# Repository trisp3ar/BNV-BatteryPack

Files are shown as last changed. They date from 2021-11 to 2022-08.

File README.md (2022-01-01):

*Harware status*: passing

*Model status*: passing

# BNV-BatteryPack

This is the Bootleg Night Vision Battery Pack, based on L3HARRIS BATTERY POWER SUPPLY for PVS 31, GPNVG 18, etc.

This design is a work in progress.

## Open Source Night Vision

This design is an open source design and everyone is welcome to build, modify and experiment on their own. It is intended to be used with the BPNVGs but can also be used with anything that uses 12 V input. Everything you need will be listed in the documentation.

## Specifications: (datasheet will be added with Release 1.0)

- Output voltage      : 12 V
- Batteries           : 4 x 18650 or CR123A
- Current Output      : 1.25 A
- protection index    : IP68 (planned/unverified)
- Dimensions          : 111 mm y 97 mm x36 mm
- Weight (empty)      : 115 g

01.01.2022

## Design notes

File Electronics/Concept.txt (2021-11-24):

Voltage Output	: 12 V
Batteries		: 18650, CR123A
Current delivery: Display	: 50 mA
				  Sensor	: 95 mA
				  Total		: 580 mA

Voltage Regulator IC		: MIC2937A-12WU, TL751M12QKVURQ1
reverse polarity protection : BAS20,235
Battery contact sping		: 5202
Battery contact flat		: 5224
Power Switch				: APEM 21136NA
Power Jack					: MIC2937A-12WU
Power Plug					: S761KS15

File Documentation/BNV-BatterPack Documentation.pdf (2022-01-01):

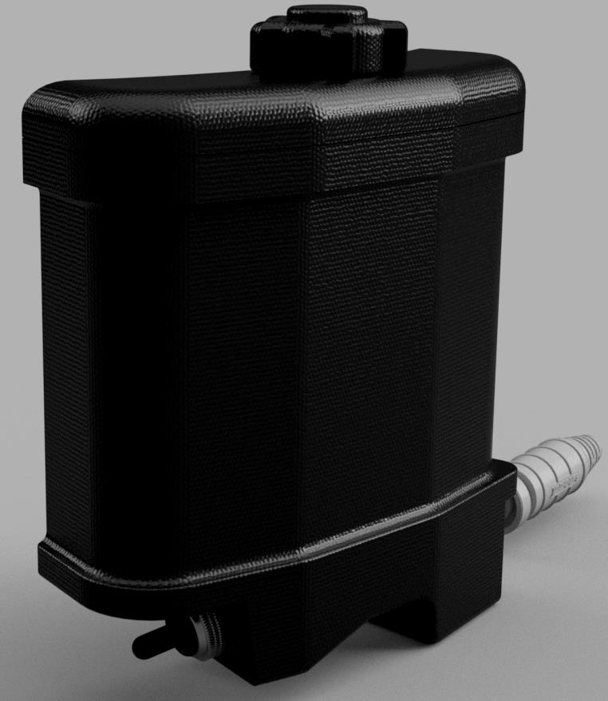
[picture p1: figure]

Gregor Hermani | 01.01.2022

# BNV-Battery Pack

Bootleg Night Vision Battery Pack

General Description

The BNV-Battery Pack is an open-source battery pack designed for use with night vision equipment in mind. It is meant to be a DIY solution for replacing a common analog night vision battery pack. With a 3D-printed case it is an easy and cheap solution. No shortcuts have been made in performance compared to commercially available night vision battery packs. It is waterproof, dustproof and airproof, as well as shock and weather resistant. The bigger body will except larger cells and can therefor provide up to 14 000 mAh.

Specifications

Voltage Output | : 12 V
Batteries | : 4 x 18650, 8 x CR123A
Current output | : 1.25 A
Protection class | : IP68 (planned/unverified)
Dimensions | : 111 mm x 97 mm x 36 mm
Weight (empty) | : 115 g

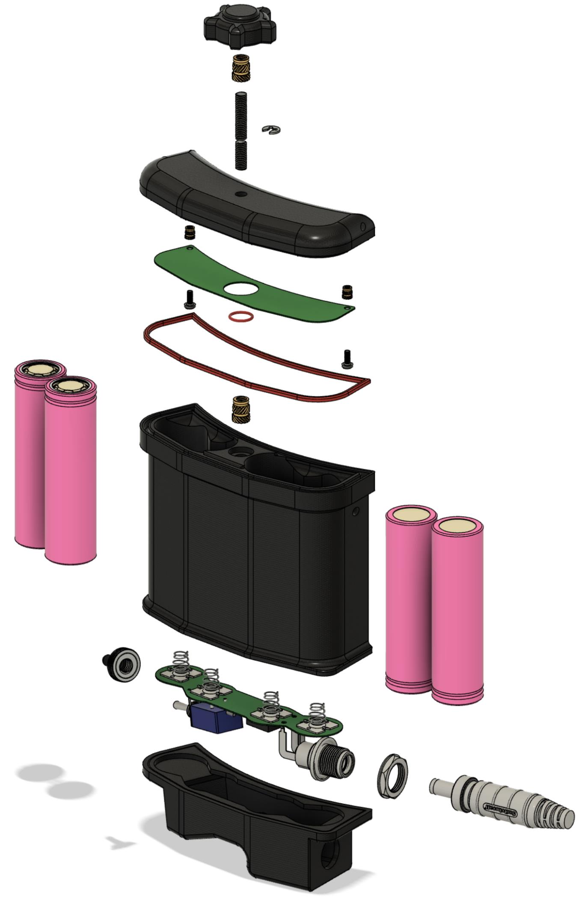
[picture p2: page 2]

Assembly

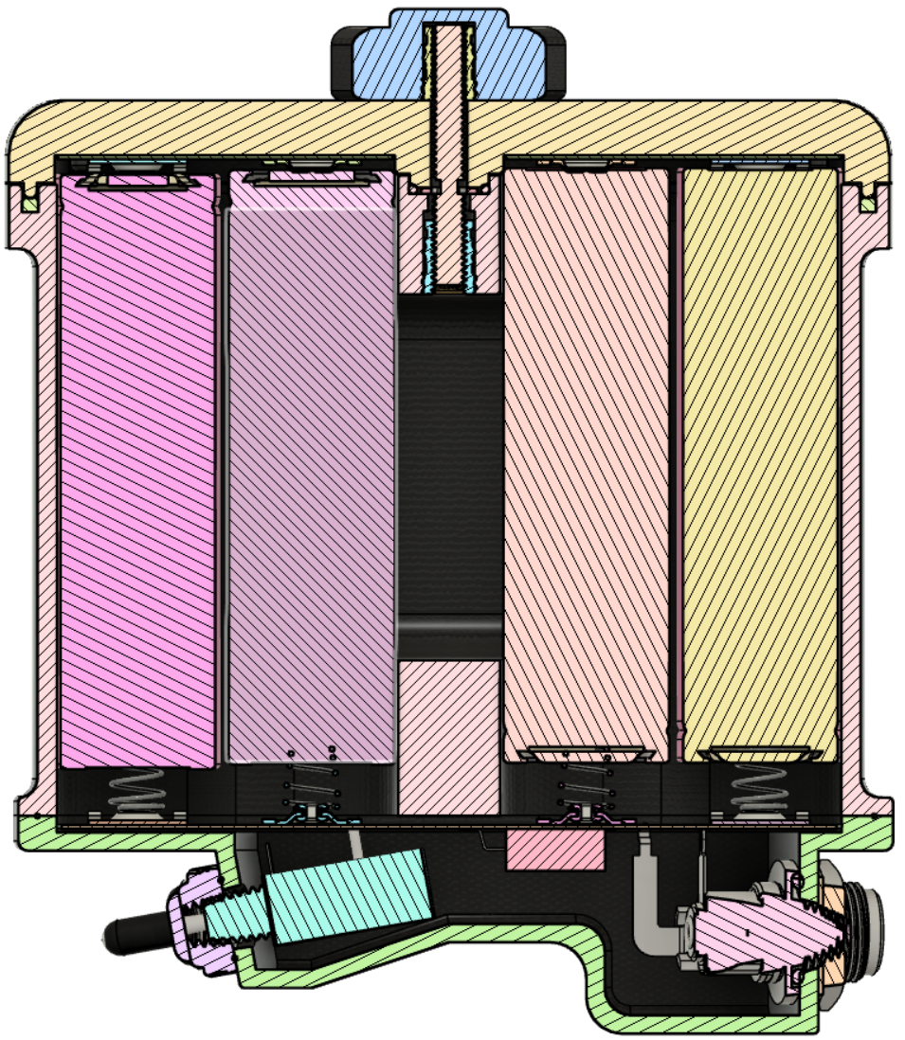
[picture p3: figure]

Development data and configuration

The designed purpose for this battery pack is power supply for night vision utilizing cameras for image acquisition and NTSC/PAL displays for video output.

Usable hardware with corresponding power consumption data and calculation for Bootleg Panoramic Night Vision Goggles:

manufacturer | part | model | current draw @ 12 V
Adafruit | display | 911 | 50 mA
Adafruit | display | 910 | 50 mA
Foxeer | camera | Micro Night Cat 3 | 95 mA
Runcam | camera | Night Eagle 2 Pro | 90 mA

Calculating for panoramic night vision with 4 camaras and 4 displays in parallel with highest current draw.

4 x 50 mA

4 x 95 mA

580 mA

To calculate for additional IR illumination, it is useful to add at least 20 % of power output capability.

battery pack schematic

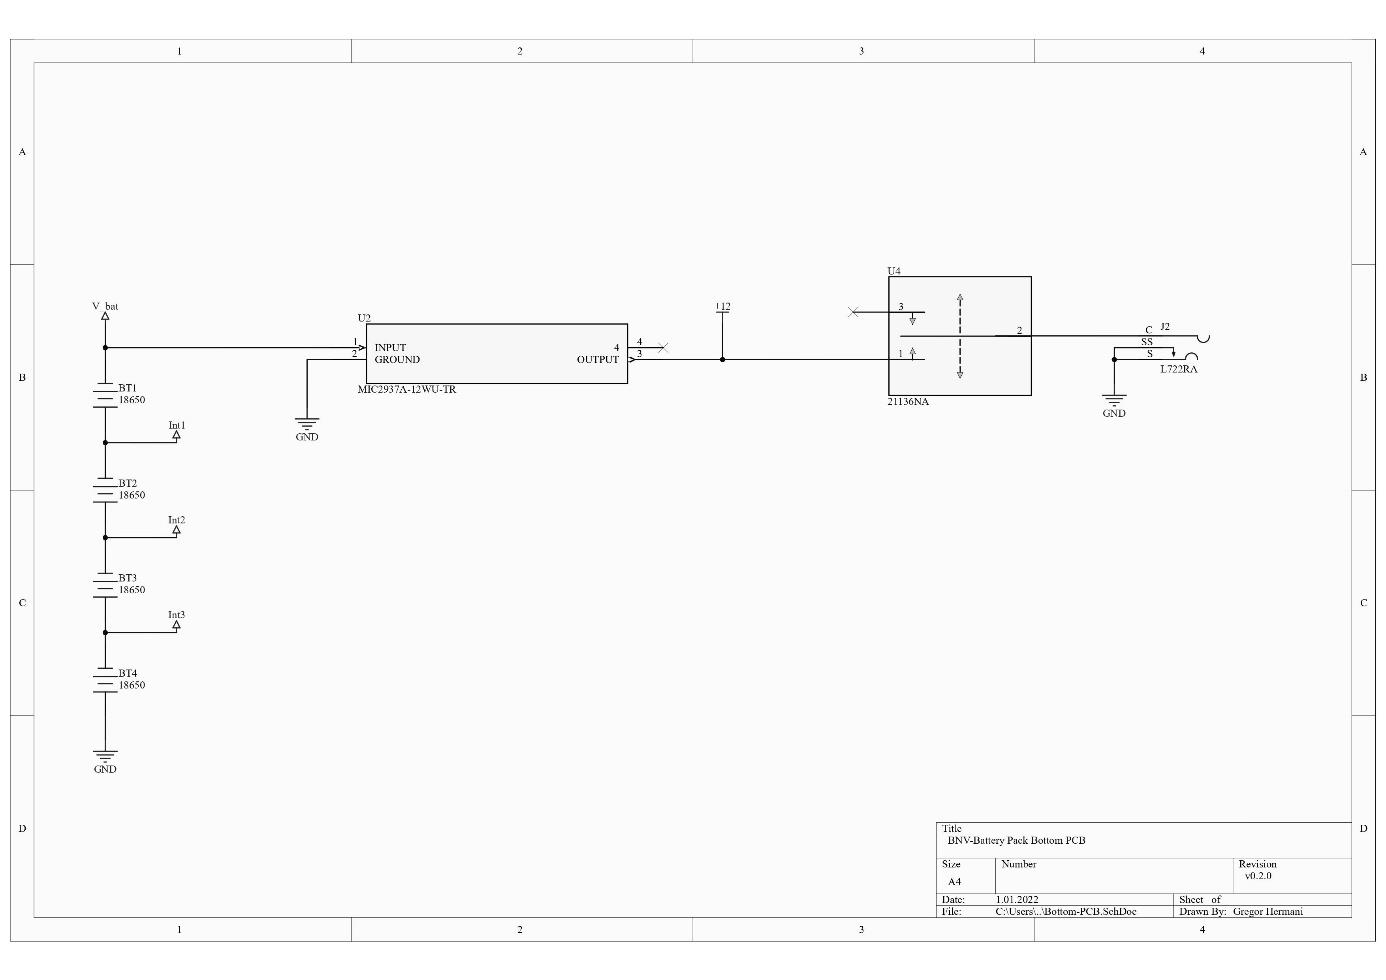
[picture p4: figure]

Version tracking and change log

v0.1.0 - initial version

v0.2.0 - changed cell configuration from 2P2R to 4R, removed diode

ToDo

- undercurrent protection
- relocate switch
- add assembly guide

Disclaimer:

This an open-source project, all information is provided without warranty.

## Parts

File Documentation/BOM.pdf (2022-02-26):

amount | part | specifications | manufacturer | MPN | component
1 | Body | 3D print | - | -
1 | Top | 3D print | - | -
1 | Bottom | 3D print | - | -
1 | Secure Nob | 3D print | - | -
1 | M4 Bolt | DIN 913 M4x25 mm | - | -
1 | safety washer | 2.3 mm DIN 6799 | - | -
1 | top gasket | 70A | - | -
1 | Secure Nob Gasket | 7 x 1 mm | - | -
2 | screw | M2x6 ISO 7380-1 | - | -
2 | M4 thread insert | brass | - | -
2 | M2 thread insert | brass | - | -
1 | connector cap | - | Switchcraft | JCAP
1 | sealing boot | 1/4-40UNS | Apem | U1331 or similar
1 | PCB | - | - | -
1 | connector | Pin OD: 2 mm, IP68 | Switchcraft | L722RAS
| connector cover | - | Switchcraft | JCAP
1 | switch | On-On | Apem | 21136NA
1 | voltage regulator IC | In: 2-26 V, Out: 12 V | Microchip | MIC2940A-12WU
4 | battery contact spring | A, AA | Keystone Electronics | 5202
1 | Kapton/Polyimid tape | < 10 cm | - | -
1 | PCB | - | - | -
4 | battery contact | A, AA | Keystone Electronics | 5224
1 | connector | Pin OD: 2 mm, IP68 | Switchcraft | S761KS15
1 | cable | two stand, OD: 4 mm | - | -
1 | glue | 2 component epoxy | Loctite | 4090
1 | potting compound | 2 component epoxy | Höhne | PU 500/2 | recommended connector cable

This is a complete BOM for the BNV-Battery Pack. All parts needed are listed, sorted by component. All parts marked with "-" are subject to personal selection due to self-manufacturing or logistics/location.

Top PCB

Bodywork

Bottom PCB

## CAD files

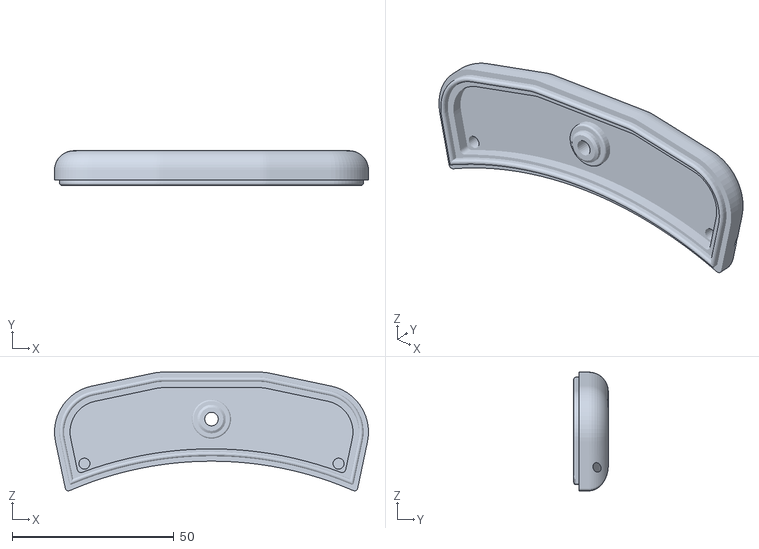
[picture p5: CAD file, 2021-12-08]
CAD/3D Printing Files/BNV-BatteryPack_Top.stl
97.0 x 10.7 x 36.7

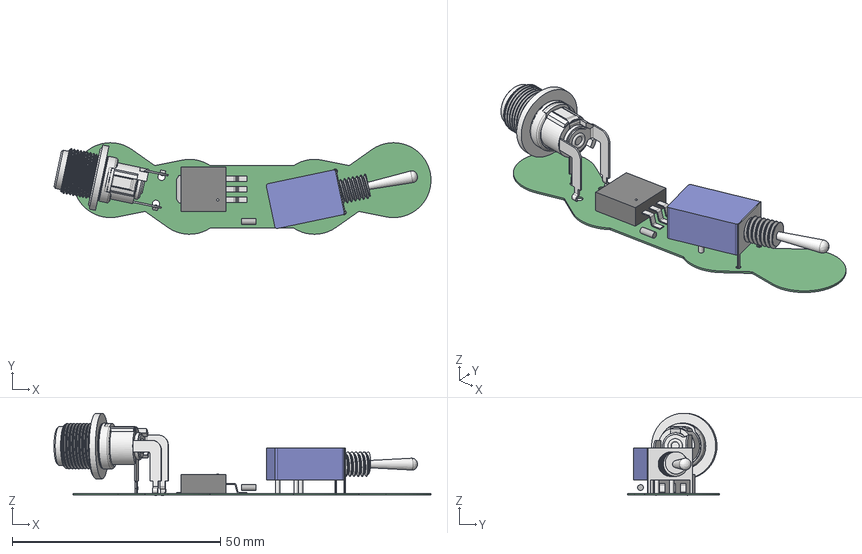
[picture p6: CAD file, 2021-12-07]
Electronics/BNV-BatteryPack_Bottom-PCB/Bottom-PCB_v0.2.0.step
90.5 x 22.0 x 19.8 mm
2113xN_v1
L722RAS

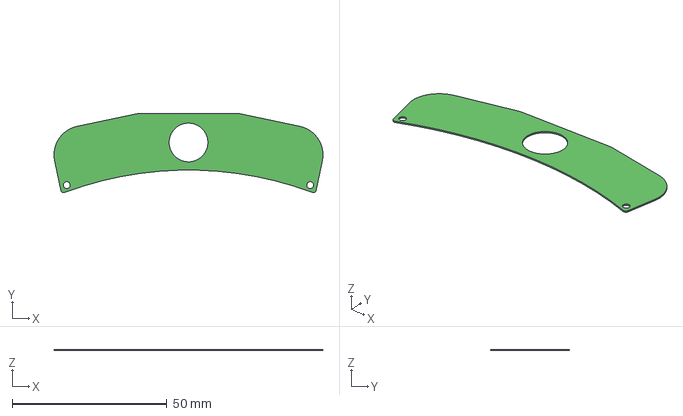
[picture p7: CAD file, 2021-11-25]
Electronics/BNV-BatteryPack_Top-PCB/Top-PCB.step
86.8 x 25.6 x 0.411 mm

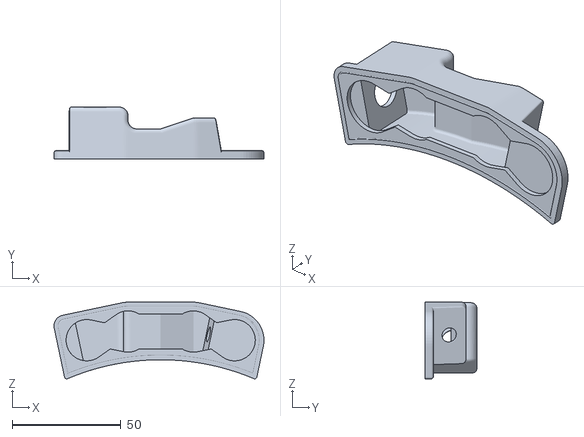
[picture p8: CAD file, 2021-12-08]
CAD/3D Printing Files/BNV-BatteryPack_Bottom.stl
96.6 x 23.8 x 35.3

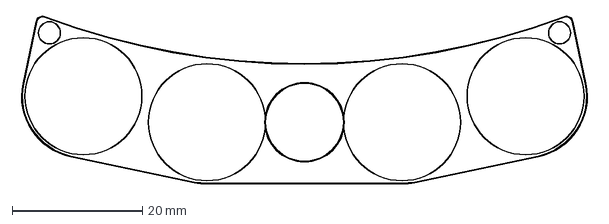
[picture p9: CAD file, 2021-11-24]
Electronics/BNV-BatteryPack_Top-PCB/Top-PCB_v0.2.0.dxf
88.8 x 25.8 mm

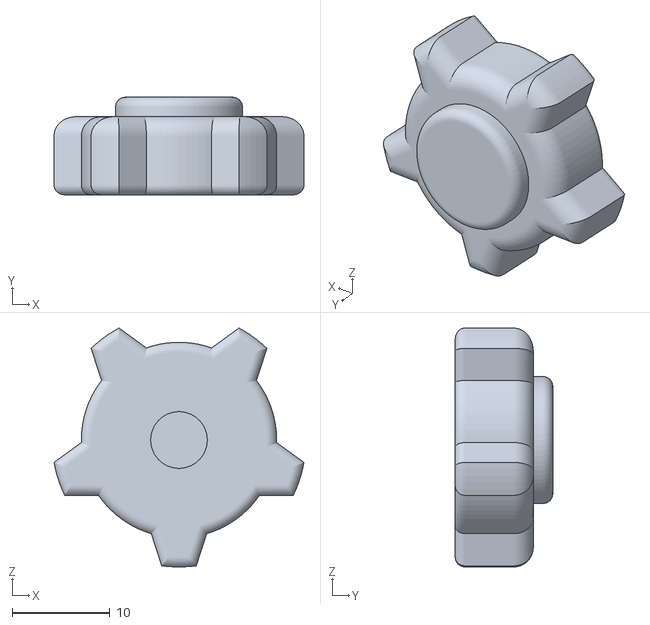
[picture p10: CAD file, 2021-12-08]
CAD/3D Printing Files/BNV-BatteryPack_SecureNob.stl
25.6 x 10.0 x 24.5

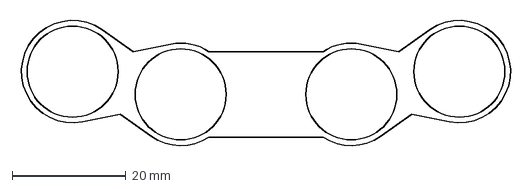
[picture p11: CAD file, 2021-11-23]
Electronics/BNV-BatteryPack_Bottom-PCB/Bottom-PCB_v0.1.2.dxf
87.8 x 23.3 mm

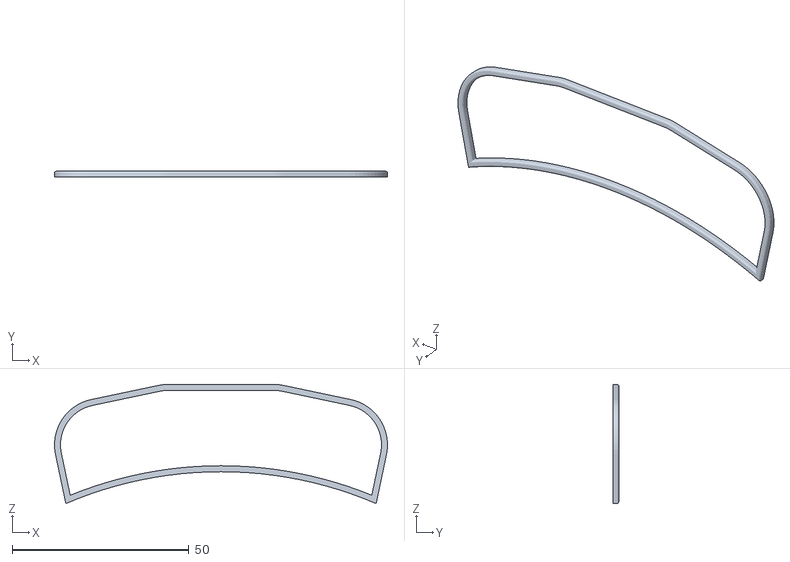
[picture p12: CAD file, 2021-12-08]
CAD/3D Printing Files/BNV-BatteryPack_TopGasket.stl
94.2 x 1.60 x 33.7

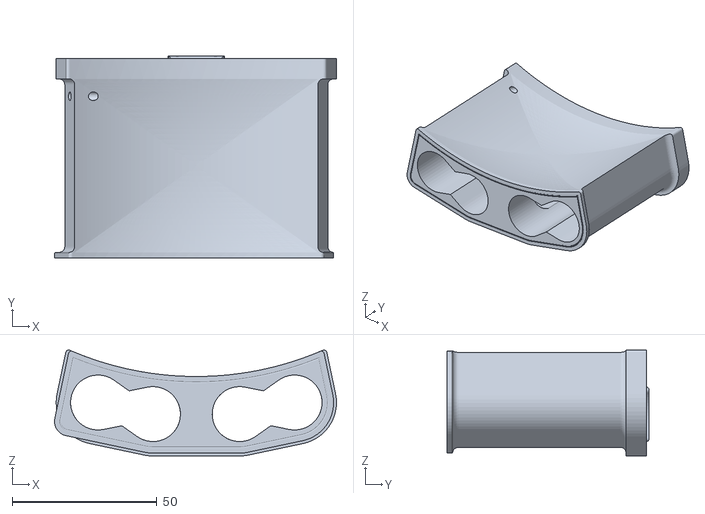
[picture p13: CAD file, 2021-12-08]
CAD/3D Printing Files/BNV-BatteryPack_Body.stl
97.6 x 70.0 x 36.7

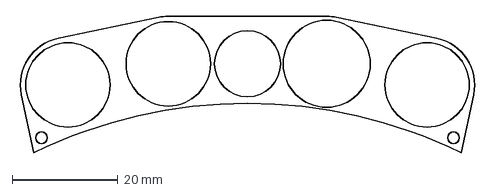
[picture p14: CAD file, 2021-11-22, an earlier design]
Electronics/BNV-BatteryPack_Top-PCB/Top-PCB_v0.1.1.dxf
87.7 x 25.8 mm

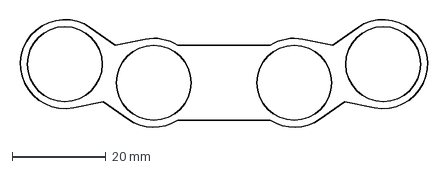
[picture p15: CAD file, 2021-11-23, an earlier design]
Electronics/BNV-BatteryPack_Bottom-PCB/Bottom-PCB_v0.1.1.dxf
88.9 x 24.3 mm

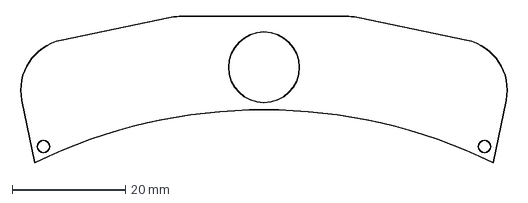
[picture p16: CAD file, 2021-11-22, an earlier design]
Electronics/BNV-BatteryPack_Top-PCB/Top-PCB_v0.1.0.dxf
87.7 x 25.8 mm

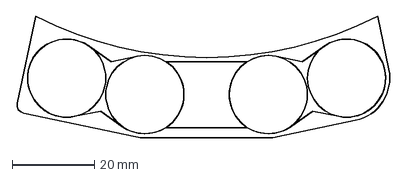
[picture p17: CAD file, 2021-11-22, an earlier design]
Electronics/BNV-BatteryPack_Bottom-PCB/Bottom-PCB_v0.1.0.dxf
91.7 x 29.5 mm

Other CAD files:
Electronics/BNV-BatteryPack_Bottom-PCB/Bottom-PCB.step

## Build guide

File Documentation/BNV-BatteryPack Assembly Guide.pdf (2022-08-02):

Gregor Hermani | 16.01.2022

# BNV-Battery Pack Assembly Guide

Bootleg Night Vision Battery Pack

General Description

This is the assembly guide for the BNV-Battery Pack. Updates will be made over time if necessary.

Parts list

Housing components

1 x | Secure Nob
1 x | Top
1 x | Main Body
1 x | Bottom
1 x | Top Gasket
1 x | DIN 913 M4 x 25
1 x | DIN 6799 2.3 mm
2 x | ISO 7380-1 M2 x 6
2 x | Thread Insert Ruthex M4
2 x | Thread Insert Ruthex M2
1x | APEM 21136NA Switch
1 x | APEM U1331 Sealing Boot
1 x | Top PCB
1 x | Switchcraft L722RAS
1 x | Switchcraft JCAP Sealing Cap
4 x | Keystone 5224 Battery Contacts
1 x | Bottom PCB
4 x | Keystone 5202 Battery Spring Contact
1 x | MIC2940A-12WU Voltage regulator

Other resources

Kapton/Polyimid Tape, High Performance Glue (i.e. Loctite 3090), Potting compound, Thread locker

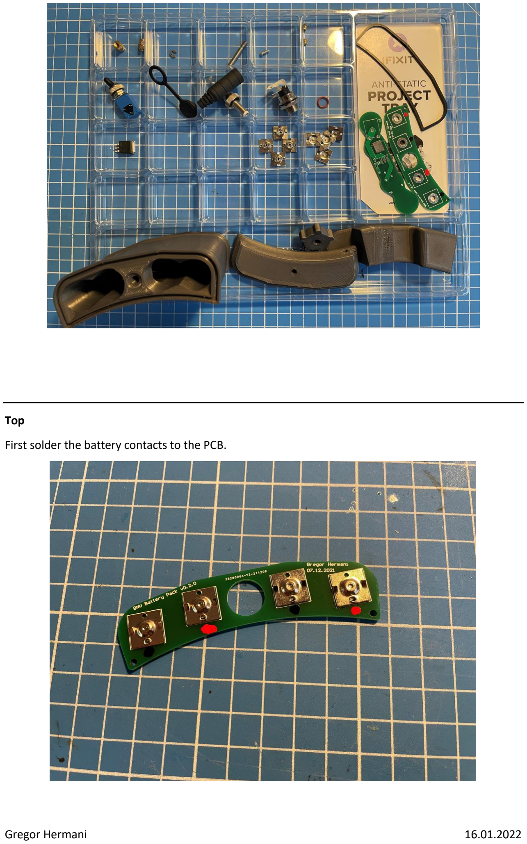
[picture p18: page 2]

Top

First solder the battery contacts to the PCB.

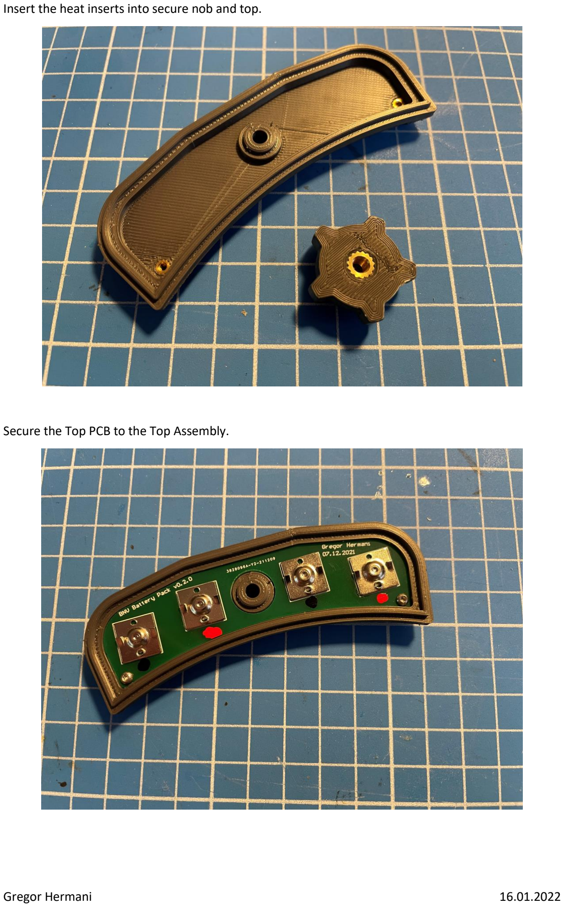
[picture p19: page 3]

Insert the heat inserts into secure nob and top.

Secure the Top PCB to the Top Assembly.

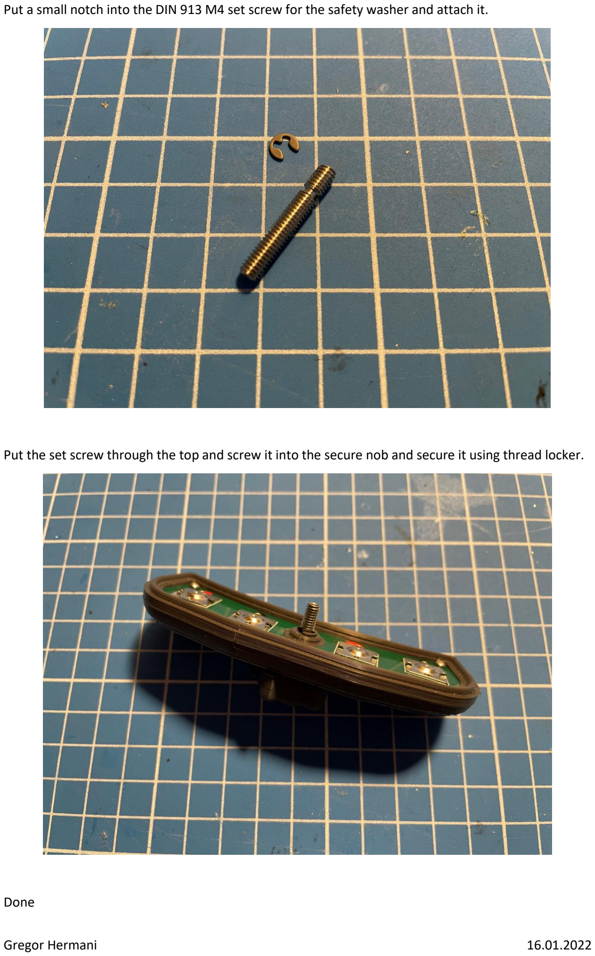
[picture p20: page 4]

Put a small notch into the DIN 913 M4 set screw for the safety washer and attach it.

Put the set screw through the top and screw it into the secure nob and secure it using thread locker.

Done

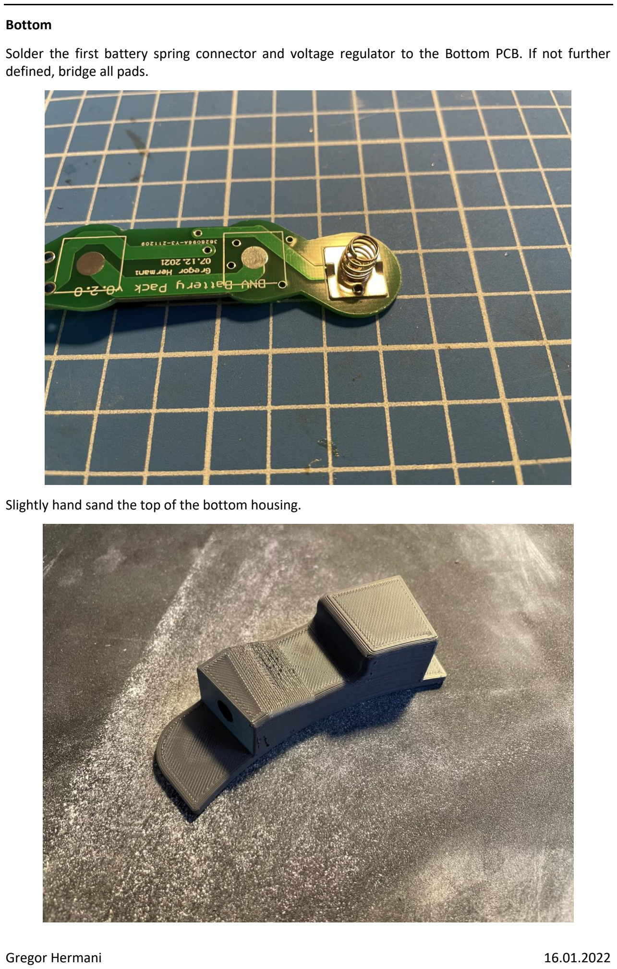
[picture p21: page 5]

Bottom

Solder the first battery spring connector and voltage regulator to the Bottom PCB. If not further defined, bridge all pads.

Slightly hand sand the top of the bottom housing.

When printed using FDM, I like to put a little super glue on the surfaces first, to level out irregularities.

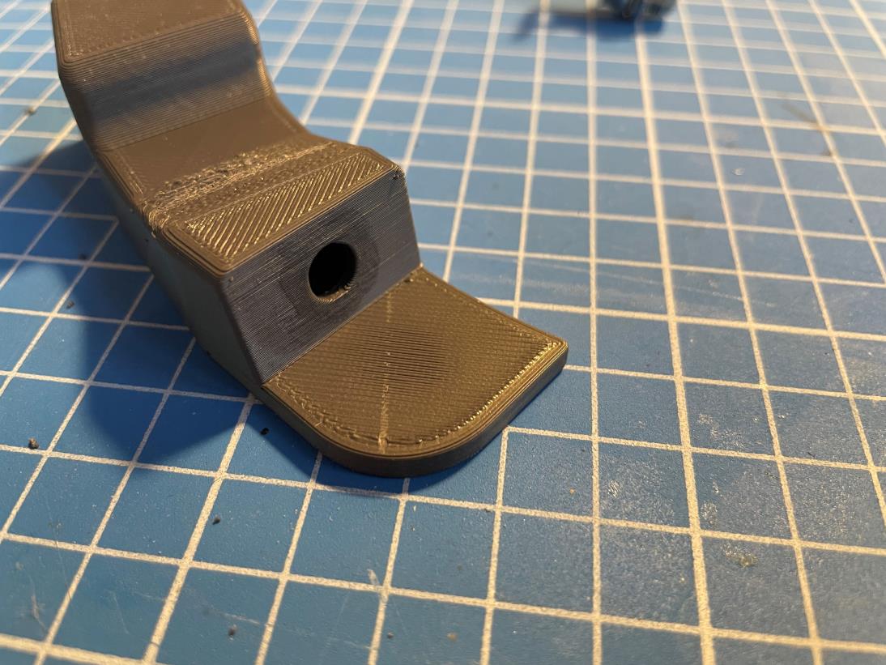
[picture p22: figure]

Put connector and switch into the bottom housing and secure them tight!

- I missed taking that picture, sorry!

Check for fitment if necessary. Also, if required, pot the bottom assembly.

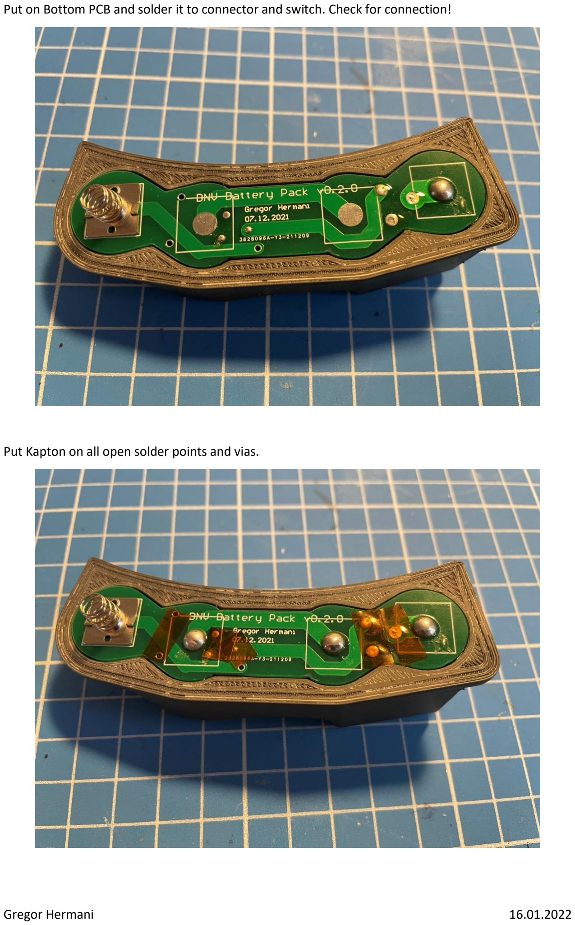
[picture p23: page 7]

Put on Bottom PCB and solder it to connector and switch. Check for connection!

Put Kapton on all open solder points and vias.

Solder the three remaining spring contacts to the board.

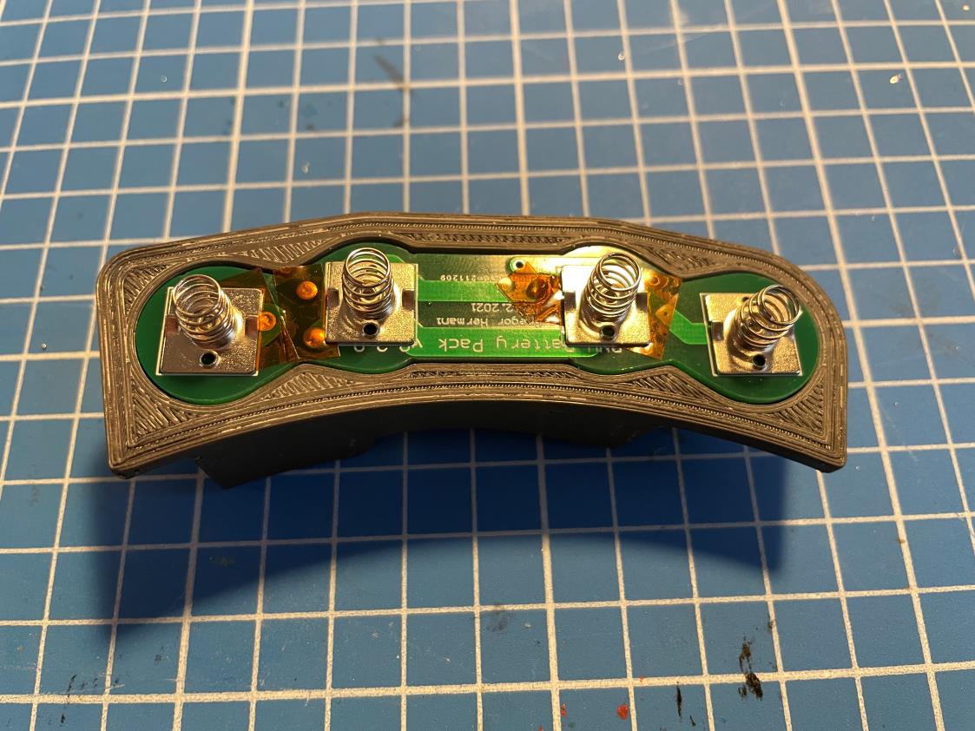
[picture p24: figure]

Done!

Main Housing

Slightly hand sand the bottom of the main housing.

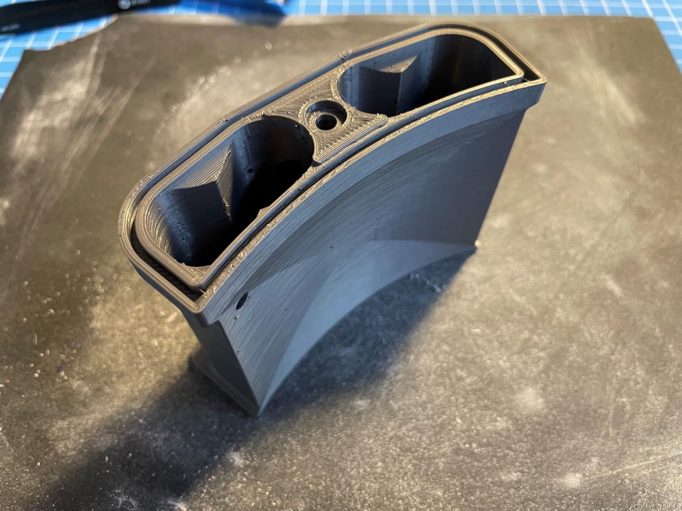
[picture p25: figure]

Insert the M4 thread insert into the prepared hole from the bottom!

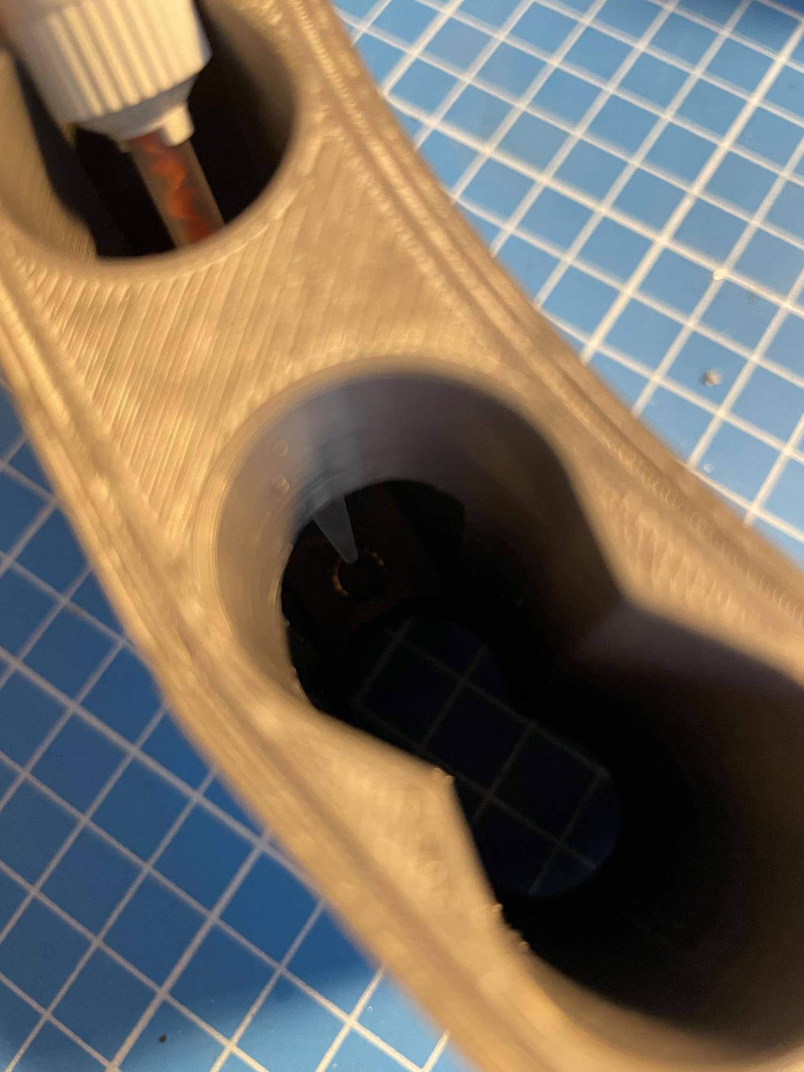
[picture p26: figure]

Use a little shim to put on the bottom of the thread insert.

Put glue into the remaining cavity. This will insure waterproofness.

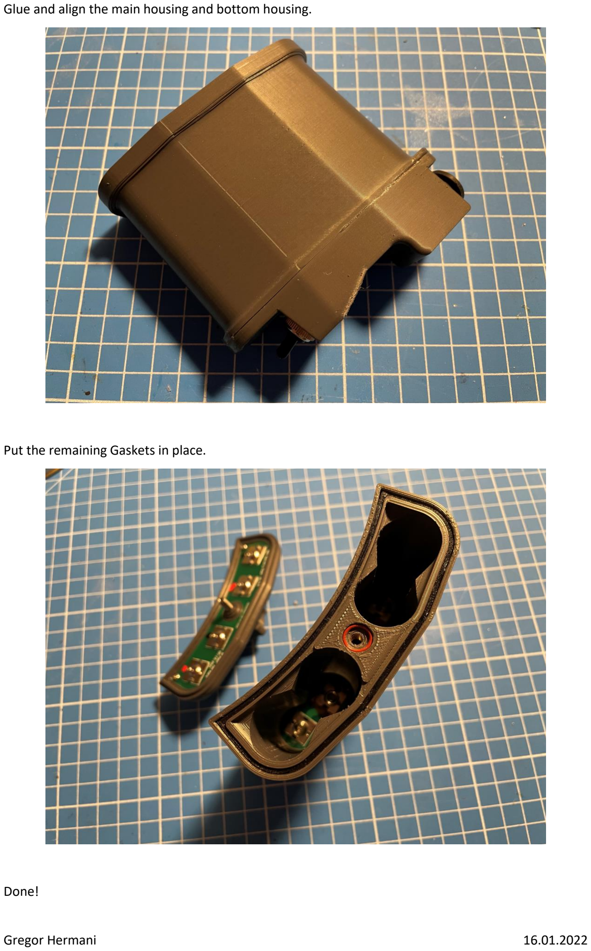
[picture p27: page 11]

Glue and align the main housing and bottom housing.

Put the remaining Gaskets in place.

Done!

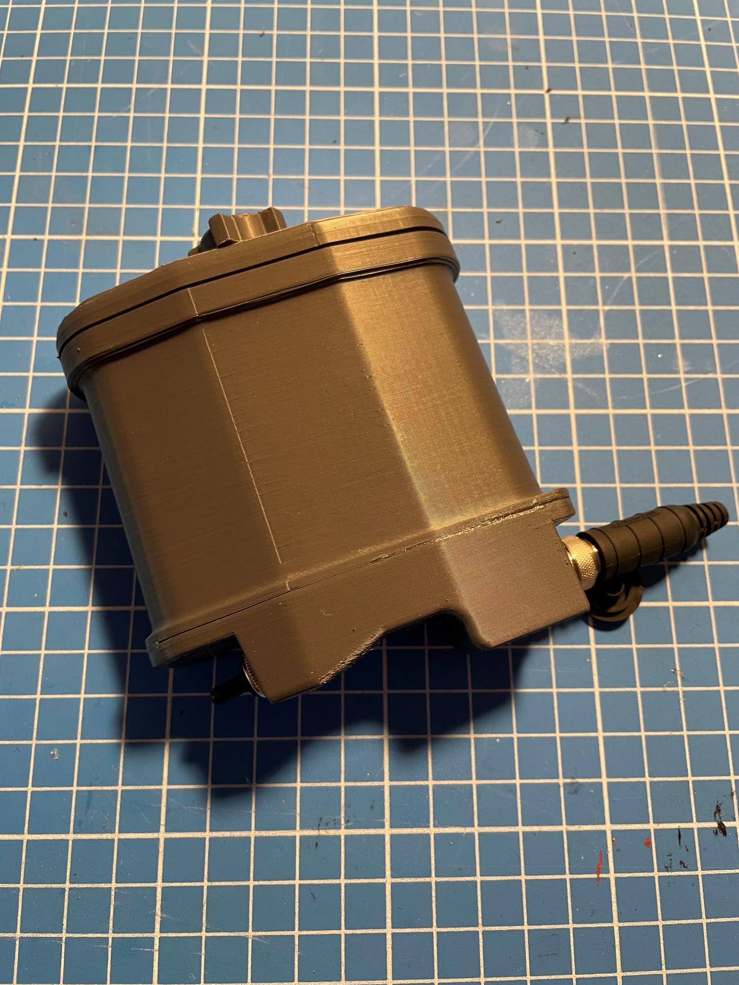
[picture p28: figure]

Now you can add a lanyard if required.

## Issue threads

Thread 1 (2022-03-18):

PCB Thickness

NateS415, 2022-03-18:
When ordering PCBs, what thickness did this design use?

trisp3ar, 2022-03-18:
The case is designed for 1.55 mm of PCB thickness, as visible in the CAD model. Of course you are free to edit the model to accommodate thicker PCBs if required.

Closed 2022-03-18.

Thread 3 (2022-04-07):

Hardware-Changes

trisp3ar, 2022-04-07:
- [ ] add cap to voltage regulator
- [ ] change schematic position of switch

trisp3ar, 2022-04-07:
ElKo:
- WE - 865090368008
- Cornell Dubilier - AVE106M16A12T-F

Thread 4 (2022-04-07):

Add undervoltage protection

trisp3ar, 2022-04-07:

trisp3ar, 2022-04-07:
Analog Devices under voltage protection:

https://www.analog.com/en/technical-articles/battery-protection-circuit.html

trisp3ar, 2022-04-16:
Finalized undervoltage protection for 18650 and CR123A batteries.

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

trisp3ar, 2022-04-16:
Adapted model for 2S2P

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

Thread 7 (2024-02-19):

Housing Too Short

southpaw12590, 2024-02-19:
I printed in black eSun ABS+, and there seems to be a 2-4mm gap between the main body and the assembled top when 4 18650s are installed, even when pushing down onto the contact springs as hard as possible. The other printed components fit their electronics perfectly, specifically the Z-axis of the bottom PCB assembly. Everything was printed all at once, so I don't think it was an issue with the printer's Z axis. I might try to stretch the main body in the slicer and print again, it doesn't look like that would throw off any critical dimensions. What brand 18650s did you use? Maybe that has something to do with it?

trisp3ar, 2024-02-19:
Hi,
this is an issue I have never encountered before. How is your fit of the top cover on the main body?

The batteries I was using were either Samsung INR18650-35E or Panasonic NCR18650B.

southpaw12590, 2024-02-19:
Thanks for replying so fast. The fit between the top assembly and the body looks to be perfect. The lip on the top assembly fits neatly into the recess on the body, and presses against the printed gasket. With no 18650s in the body, the top closes with no gaps. I'm attaching pictures. In the two pics with the printed knob, there are no batteries. In the two using the M4 bolt, you can slightly see the batteries, and the bolt is tightened as much as it can be without cracking plastic.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

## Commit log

2021-11-22 initial Push
    [BNV-BatteryPack_BottomPCB.PrjPcb, BNV-BatteryPack_TopPCB.PrjPcb, Bottom-PCB.PcbDoc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]
2021-11-23 Altium, fist PCBs
    [BNV-BatteryPack_BottomPCB.PrjPcb, BNV-BatteryPack_TopPCB.PrjPcb, Bottom-PCB.PcbDoc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]
2021-11-23 Top-PCB done, Bottom-PCB done, layout & schematic
    [Bottom-PCB.PcbDoc, Bottom-PCB.SchDoc, Bottom-PCB.step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]
2021-11-24 Bottom-PCB update, Problem found: Switch Gasket too big for PCB, revision needed
    [Bottom-PCB.PcbDoc, Bottom-PCB.SchDoc, Bottom-PCB.step]
2021-11-24 Add Datasheets and PCB update
    [Bottom-PCB.PcbDoc]
2021-11-24 last commit before housing update
    [Top-PCB.PcbDoc, Top-PCB_v0.2.0.dxf]
2021-11-25 Top-PCB.PcbDoc add polarity
    [Top-PCB.PcbDoc, Top-PCB.step]
2021-11-25 commit Prototype A v0.1.0 documentation added
    [BNV-BatteryPack_BottomPCB.PrjPcb, BNV-BatteryPack_TopPCB.PrjPcb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]
2021-11-27 CAD update
    [Bottom-PCB.SchDoc]
2021-11-28 add BOM
2021-12-03 update BOM
2021-12-04 update CAD model, top gasket, bottom
2021-12-04 CAD model
2021-12-04 update BOM, added Kapton
2021-12-07 Schematic and layout revision all cells in series
    [Bottom-PCB.PcbDoc, Bottom-PCB.SchDoc, Top-PCB.PcbDoc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]
2021-12-07 Updated CAD model and documentation for PCB v0.2.0
    [Bottom-PCB_v0.2.0.step]
2021-12-07 Add contact placements, add diode datasheet
    [Bottom-PCB.PcbDoc, Top-PCB.PcbDoc]
2021-12-07 update docu, update schematic description
    [Bottom-PCB.SchDoc, Top-PCB.SchDoc]
2021-12-08 add 3d printing files
    [BNV-BatteryPack_Body.stl, BNV-BatteryPack_Bottom.stl, BNV-BatteryPack_SecureNob.stl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]
2021-12-09 update fabrication outputs
    [BNV-BatteryPack_BottomPCB.PrjPcb, BNV-BatteryPack_TopPCB.PrjPcb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]
2021-12-15 remove unnecessary diode
    [BNV-BatteryPack_BottomPCB.PrjPcb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]
2021-12-21 remove diode
2022-01-16 Add assembly guide
2022-04-07 correct top PCB symbols
    [BNV-BatteryPack_TopPCB.PrjPcb, Top-PCB.PcbDoc]
2022-04-07 update top PCB manufacturing files
    [BNV-BatteryPack_TopPCB.PrjPcb, Top-PCB.PcbDoc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]
2022-08-02 update Assembly Guide, add simulation 2S2P
